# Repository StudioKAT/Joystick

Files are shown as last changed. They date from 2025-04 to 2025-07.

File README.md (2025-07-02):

# Joystick
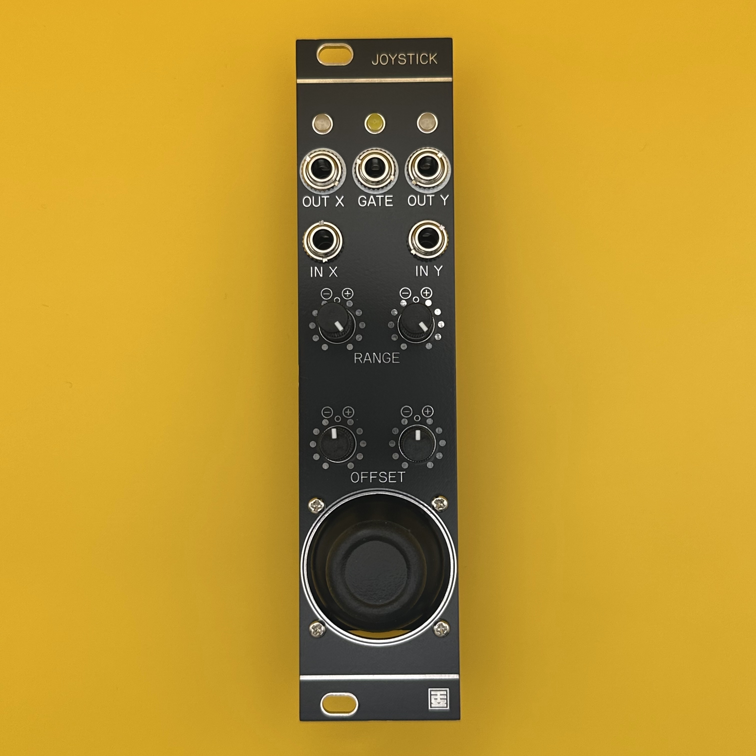
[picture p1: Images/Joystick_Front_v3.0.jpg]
Joystick Front


## 概要 / Overview

**Joystick** は、6HPサイズの片手操作に特化したマニュアルCV/Gate生成モジュールです。  
XY入力端子に外部CVを接続することで、アッテネーターやインバーターとしても利用可能です。  
CVレンジとオフセットはX軸・Y軸ごとに個別に調整でき、最大±10Vの範囲で任意のCVを生成できます。  
スティックを押し込むと、+10VのGate信号が出力されます。

**Joystick** is a 6HP manual CV/Gate generator module designed for one-handed operation.  
By connecting external CV signals to the X and Y inputs, it can also function as an attenuator or inverter.  
Each axis (X and Y) features independent control over CV range and offset, allowing for custom voltage outputs up to ±10V.  
Pressing the joystick down outputs a +10V Gate signal.

## 仕様 / Spec
- Format: Eurorack
- Function: Attenuator-Inverter joystick controller and Gate Generator.
- Current needs: +12V: 35mA, -12V: 35mA
- Width: 6 HP
- Depth: 25mm (including power connector)

## 動画 / Movie
'Joystick商品説明動画' (https://youtu.be/lRxTDCcPD24)

## 販売 / Sales

StudioKATオフィシャルショップで販売しています。(日本国内限定)  
https://www.studiokat.jp/items/106541452

## ライセンス / License

この作品は [Creative Commons 表示 - 継承 4.0 国際 (CC BY-SA 4.0)](https://creativecommons.org/licenses/by-sa/4.0/deed.ja) の下でライセンスされています。  
This work is licensed under the [Creative Commons Attribution-ShareAlike 4.0 International License](https://creativecommons.org/licenses/by-sa/4.0/).

## クレジット / Credits

- Designed by : StudioKAT
- Website : https://www.studiokat.jp/
- GitHub : https://github.com/StudioKAT
- X(Twitter) : https://x.com/StudioKAT_synth
- Instagram : https://www.instagram.com/studiokat_modular/

## 更新履歴 / Changelog

- `2024-09-28` v1.0 Unreleased
- `2025-04-24` v2.0 Released
- `2025-07-02` v3.0 Released

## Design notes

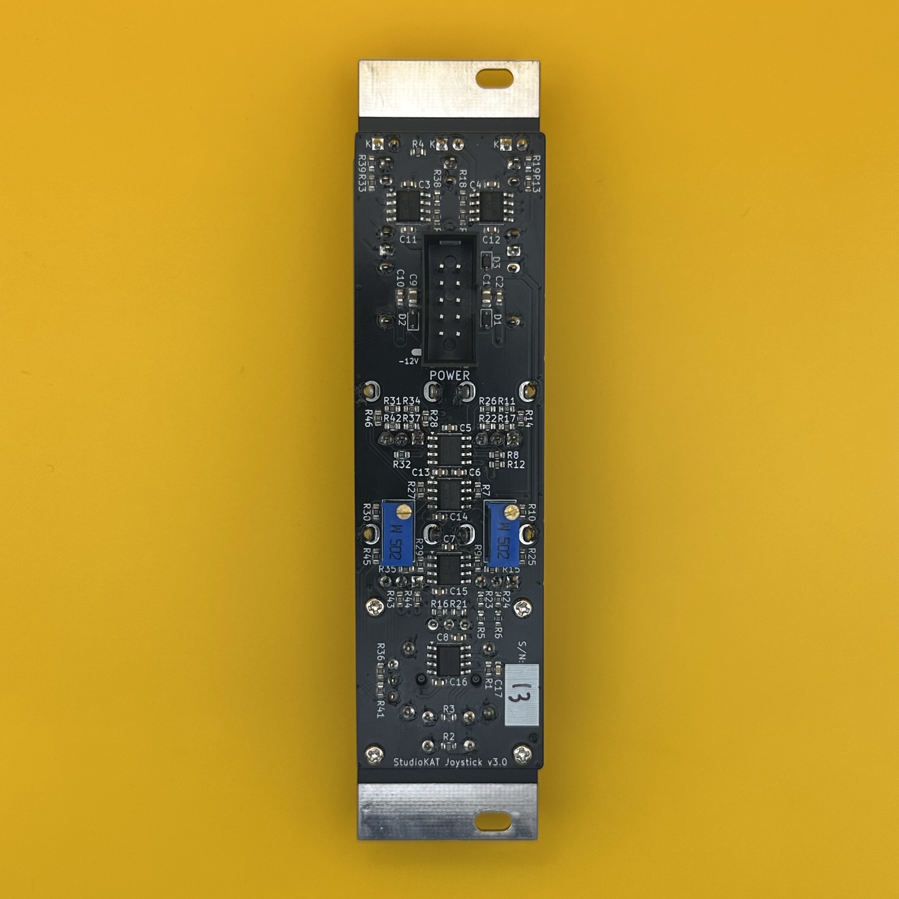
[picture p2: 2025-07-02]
Images/Joystick_Back_v3.0.jpg

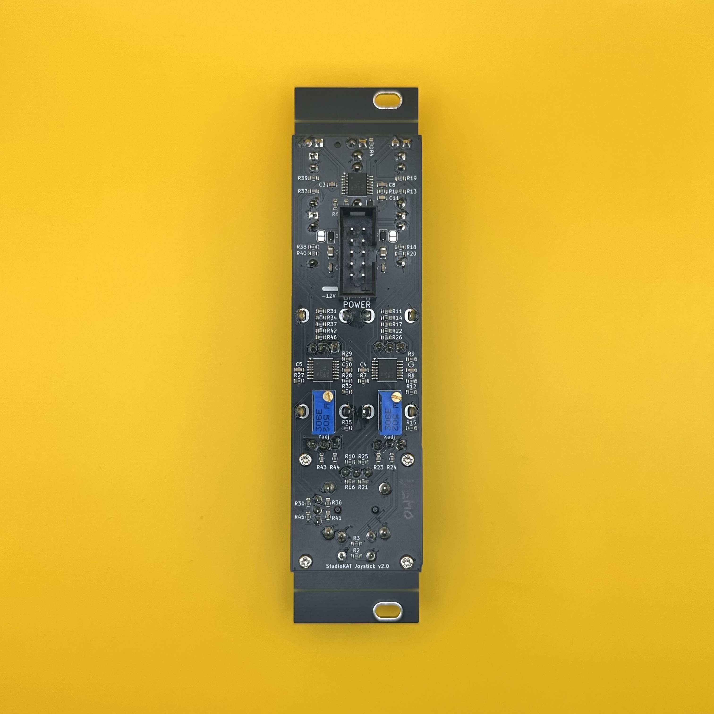
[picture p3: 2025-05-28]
Images/Joystick_Back.jpeg

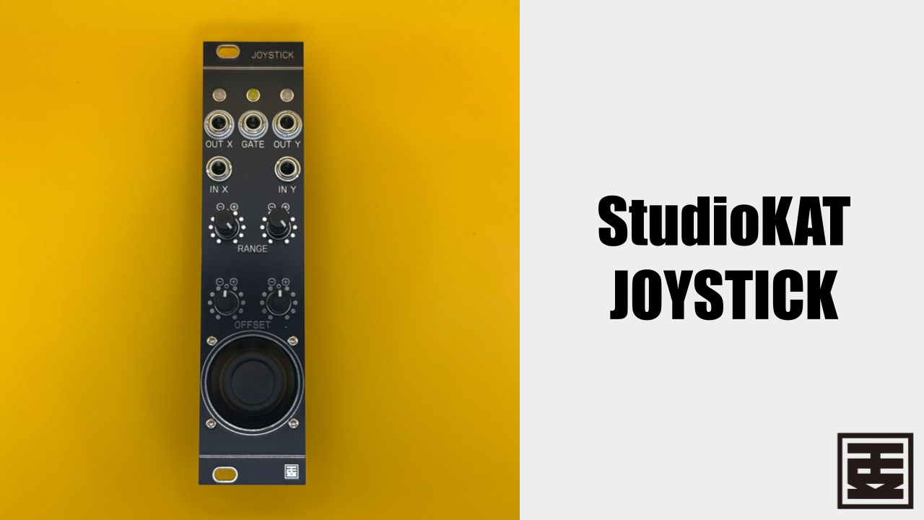
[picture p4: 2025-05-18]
Images/Joystick_thumbnail.png

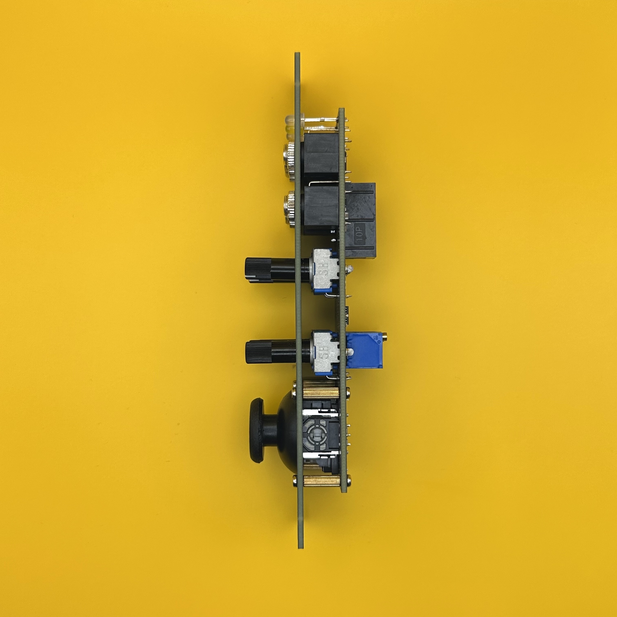
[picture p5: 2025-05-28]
Images/Joystick_Side.jpeg

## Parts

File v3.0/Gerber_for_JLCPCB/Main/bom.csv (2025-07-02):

Designator | Footprint | Quantity | Value | LCSC Part #
C1, C9 | 0805 | 2 | 22uF | C45783
C10, C11, C12, C13, C14, C15, C16, C2, C3, C4, C5, C6, C7, C8 | 0603 | 14 | 100nF | C14663
C17 | 0603 | 1 | 22nF | C21122
D1, D2 | D_SOD-323 | 2 | 1N5819WS | C191023
D3 | D_SOD-323 | 1 | 1N4148WS | C2128
D4 | LED_D3.0mm | 1 | LED
D5, D6 | LED_D3.0mm | 2 | LED_RED_GREEN
J1 | BoxHeader_2x05_2.54mm_Europower | 1 | POWER
J2 | AudioJack_PJ301M-12 | 1 | GATE
J3 | AudioJack_PJ301M-12 | 1 | X_OUT
J4 | AudioJack_PJ301M-12 | 1 | X_IN
J5 | AudioJack_PJ301M-12 | 1 | Y_OUT
J6 | AudioJack_PJ301M-12 | 1 | Y_IN
JS1 | Joystick_RKJXV122400R | 1 | RKJXV122400R
R1, R18, R38 | 0603 | 3 | 1M | C22935
R10, R12, R15, R20, R25, R27, R29, R30, R32, R35, R40, R45, R6, R7, R9 | 0603 | 15 | 10K | C25804
R11, R2, R26, R31, R46 | 0603 | 5 | 100K | C25803
R13, R23, R24, R33, R43, R44 | 0603 | 6 | 1K | C21190
R14, R34 | 0603 | 2 | 22K | C31850
R16, R36 | 0603 | 2 | 5.1K | C23186
R17, R37 | 0603 | 2 | 39K | C23153
R19, R39 | 0603 | 2 | 3.3K | C22978
R21, R41 | 0603 | 2 | 8.2K | C25981
R22, R42 | 0603 | 2 | 82K | C23254
R28, R8 | 0603 | 2 | 150K | C22807
R3 | 0603 | 1 | 470K | C23178
R4 | 0603 | 1 | 6.8K | C23212
R5 | 0603 | 1 | 4.7K | C23162
RV1, RV4 | Potentiometer_Bourns_3296W_Vertical | 2 | 5kΩ 502
RV2, RV3, RV5, RV6 | Potentiometer_RV09 | 4 | B100K
U1, U2, U3, U4, U5, U6 | SOIC-8_3.9x4.9mm_P1.27mm | 6 | TL072CDT | C6961

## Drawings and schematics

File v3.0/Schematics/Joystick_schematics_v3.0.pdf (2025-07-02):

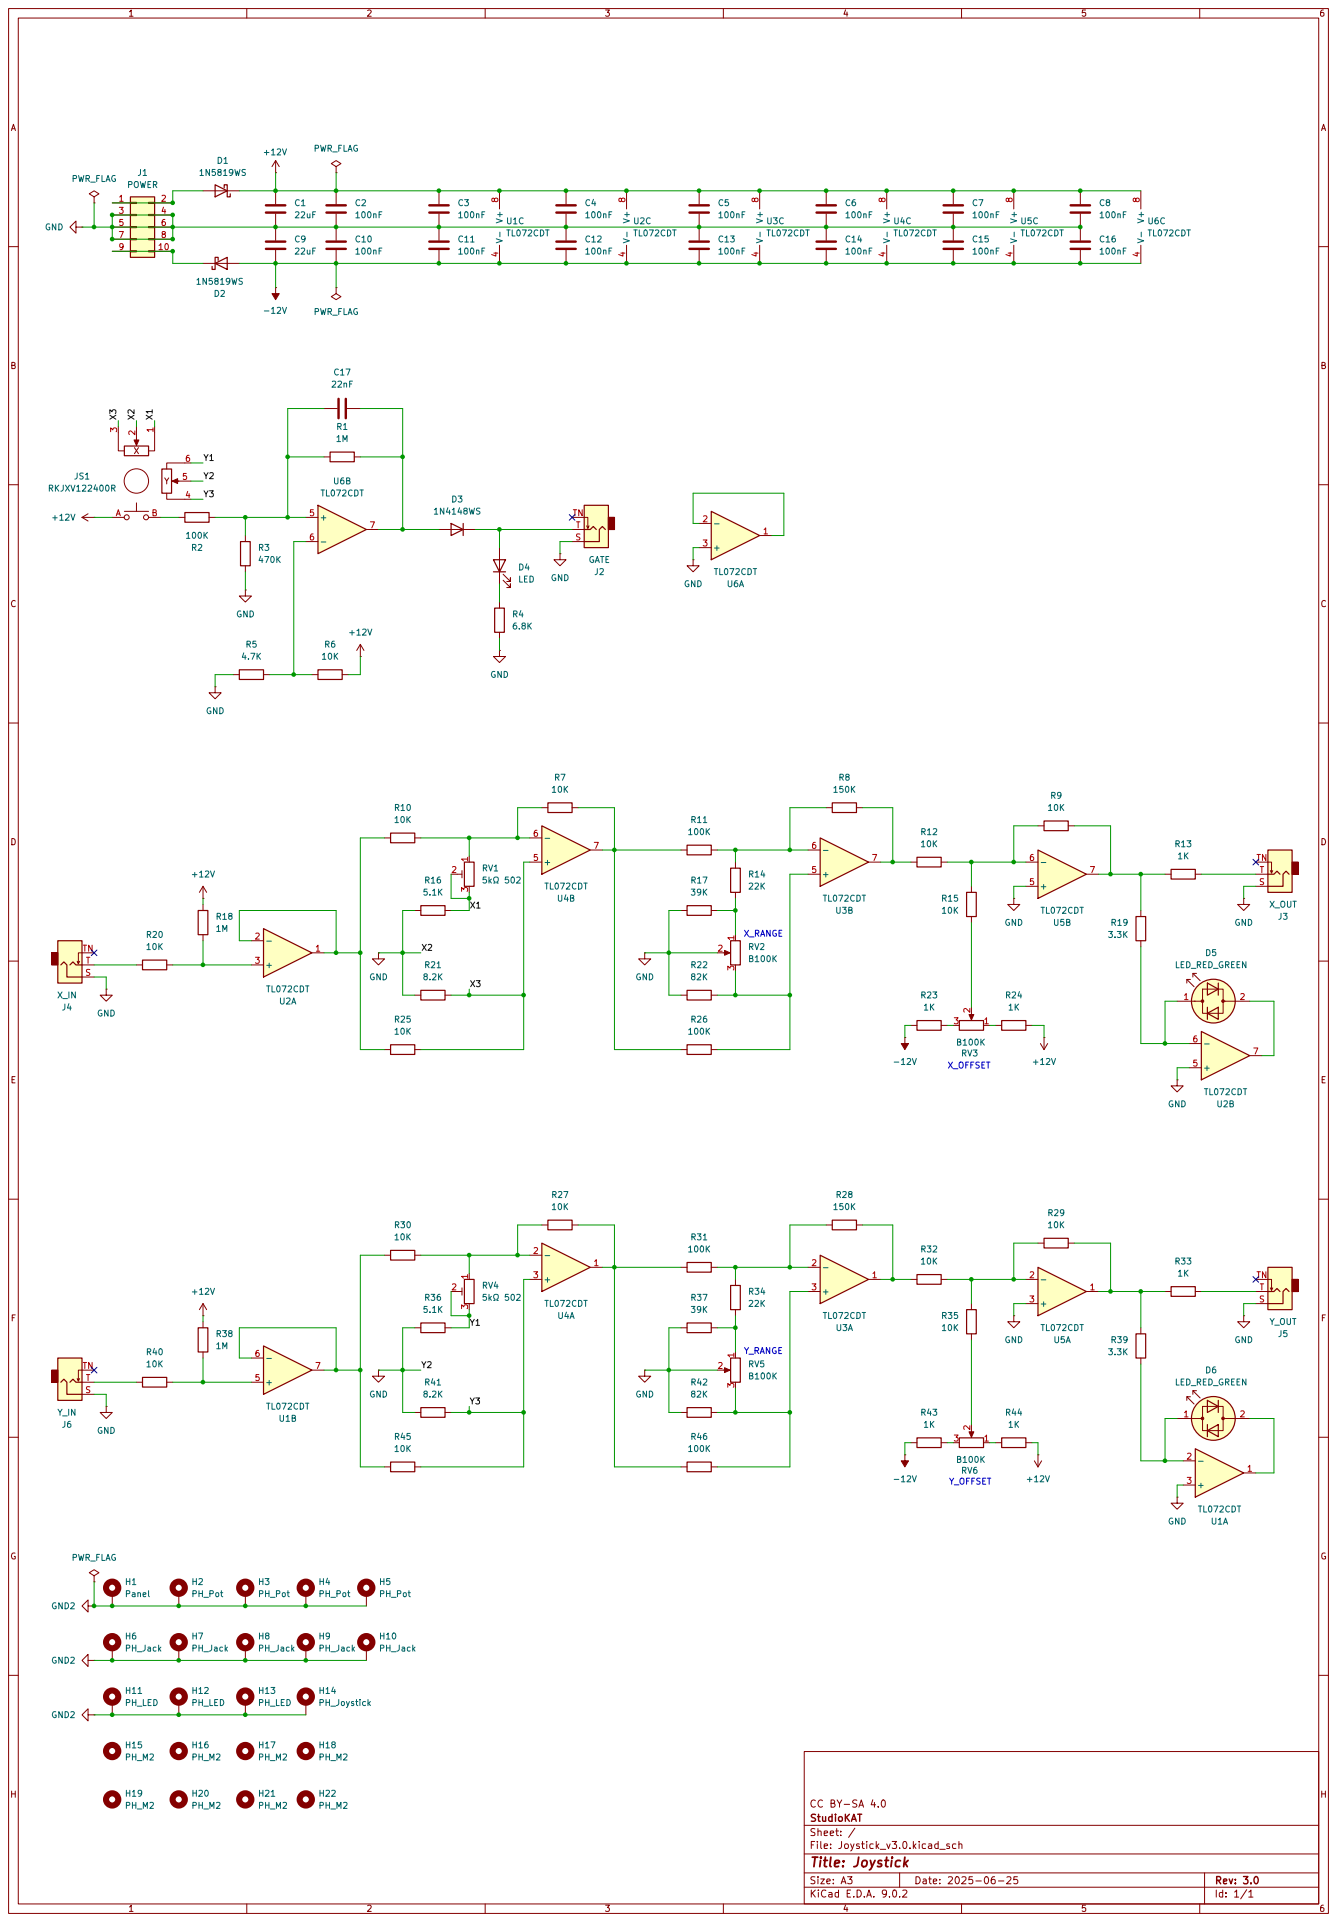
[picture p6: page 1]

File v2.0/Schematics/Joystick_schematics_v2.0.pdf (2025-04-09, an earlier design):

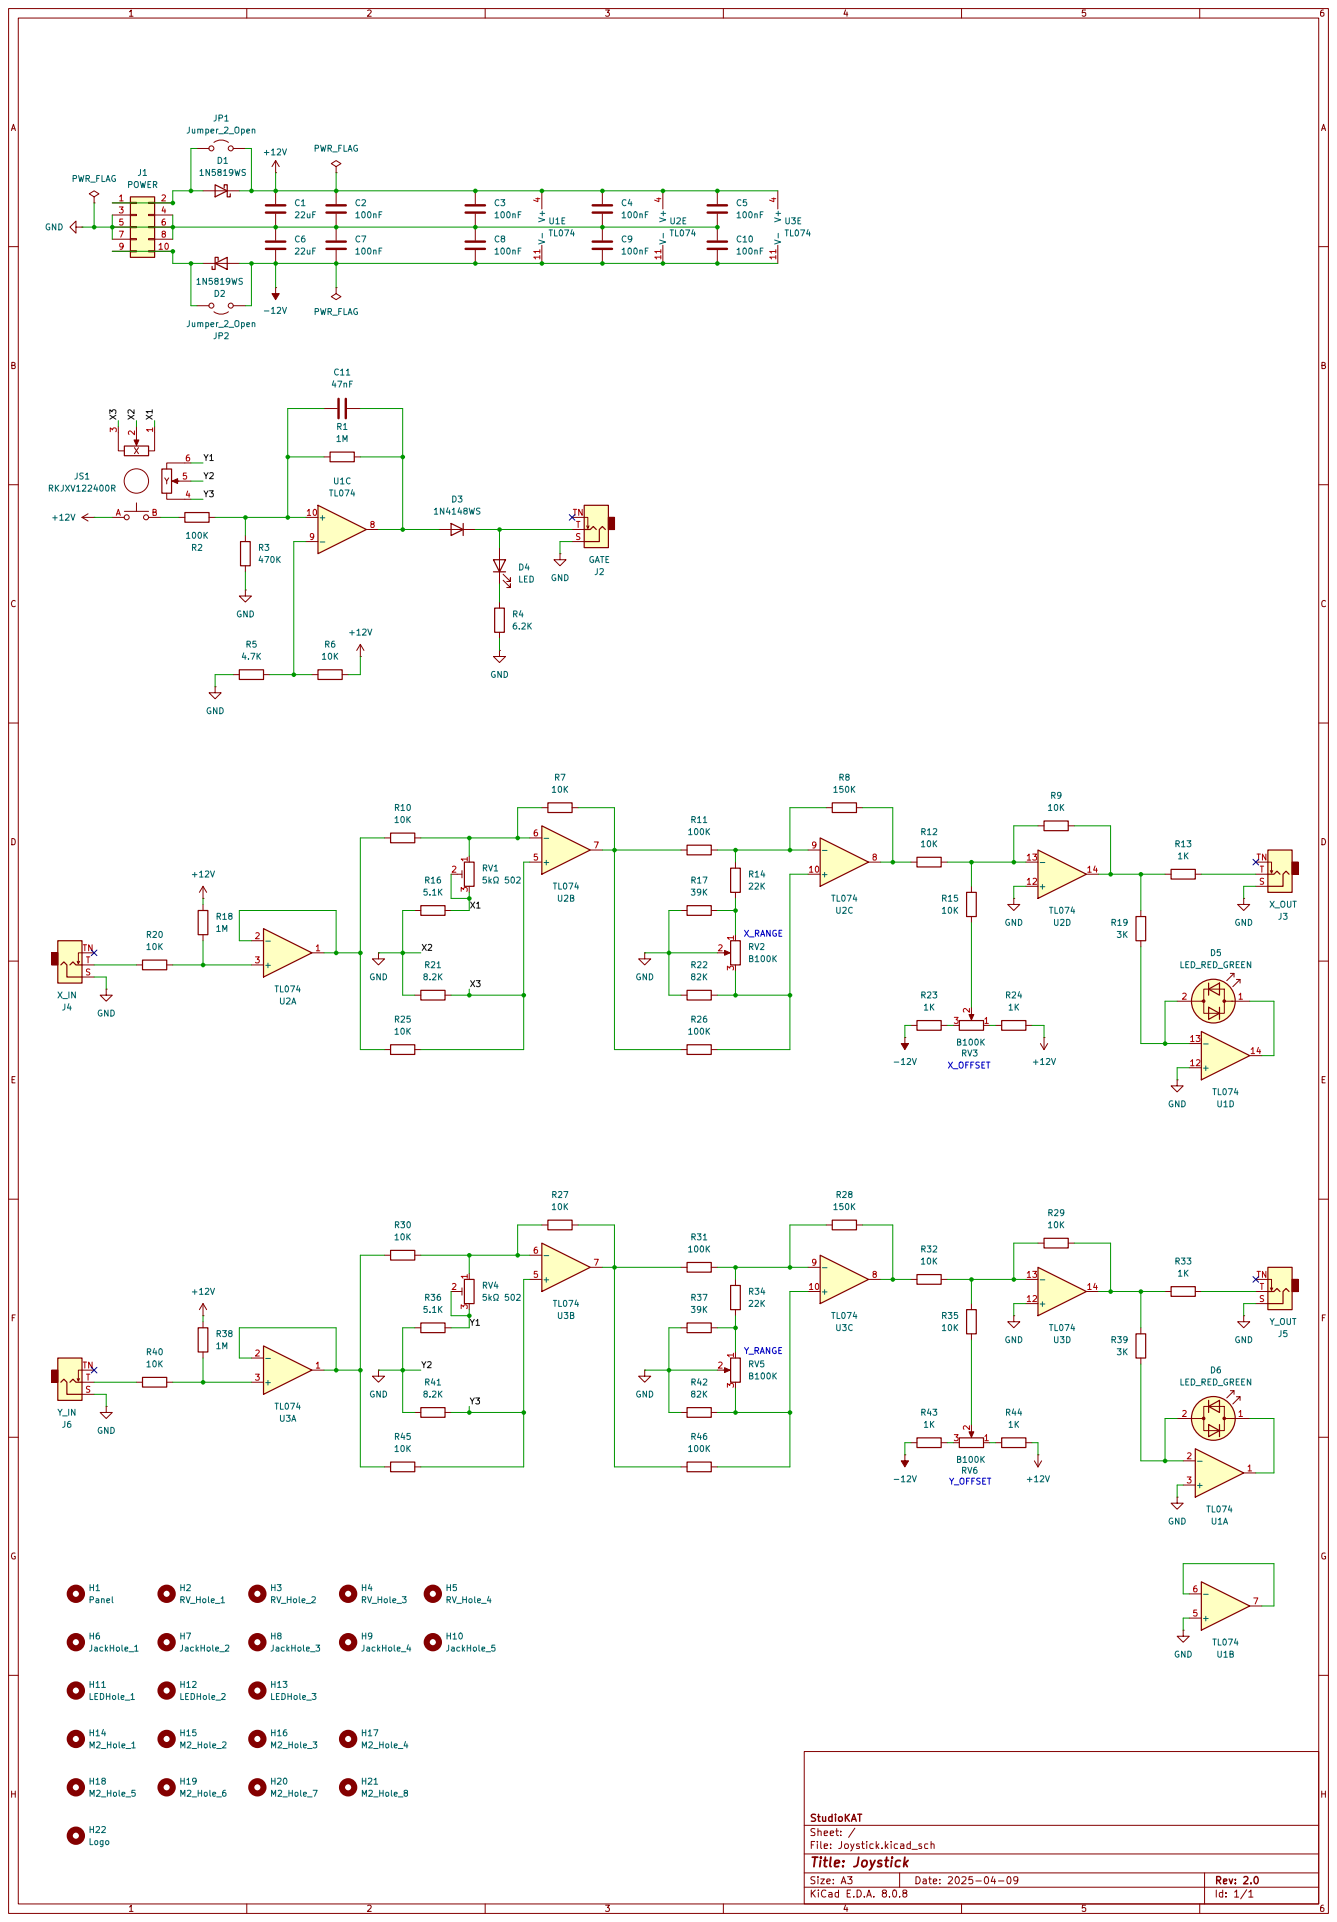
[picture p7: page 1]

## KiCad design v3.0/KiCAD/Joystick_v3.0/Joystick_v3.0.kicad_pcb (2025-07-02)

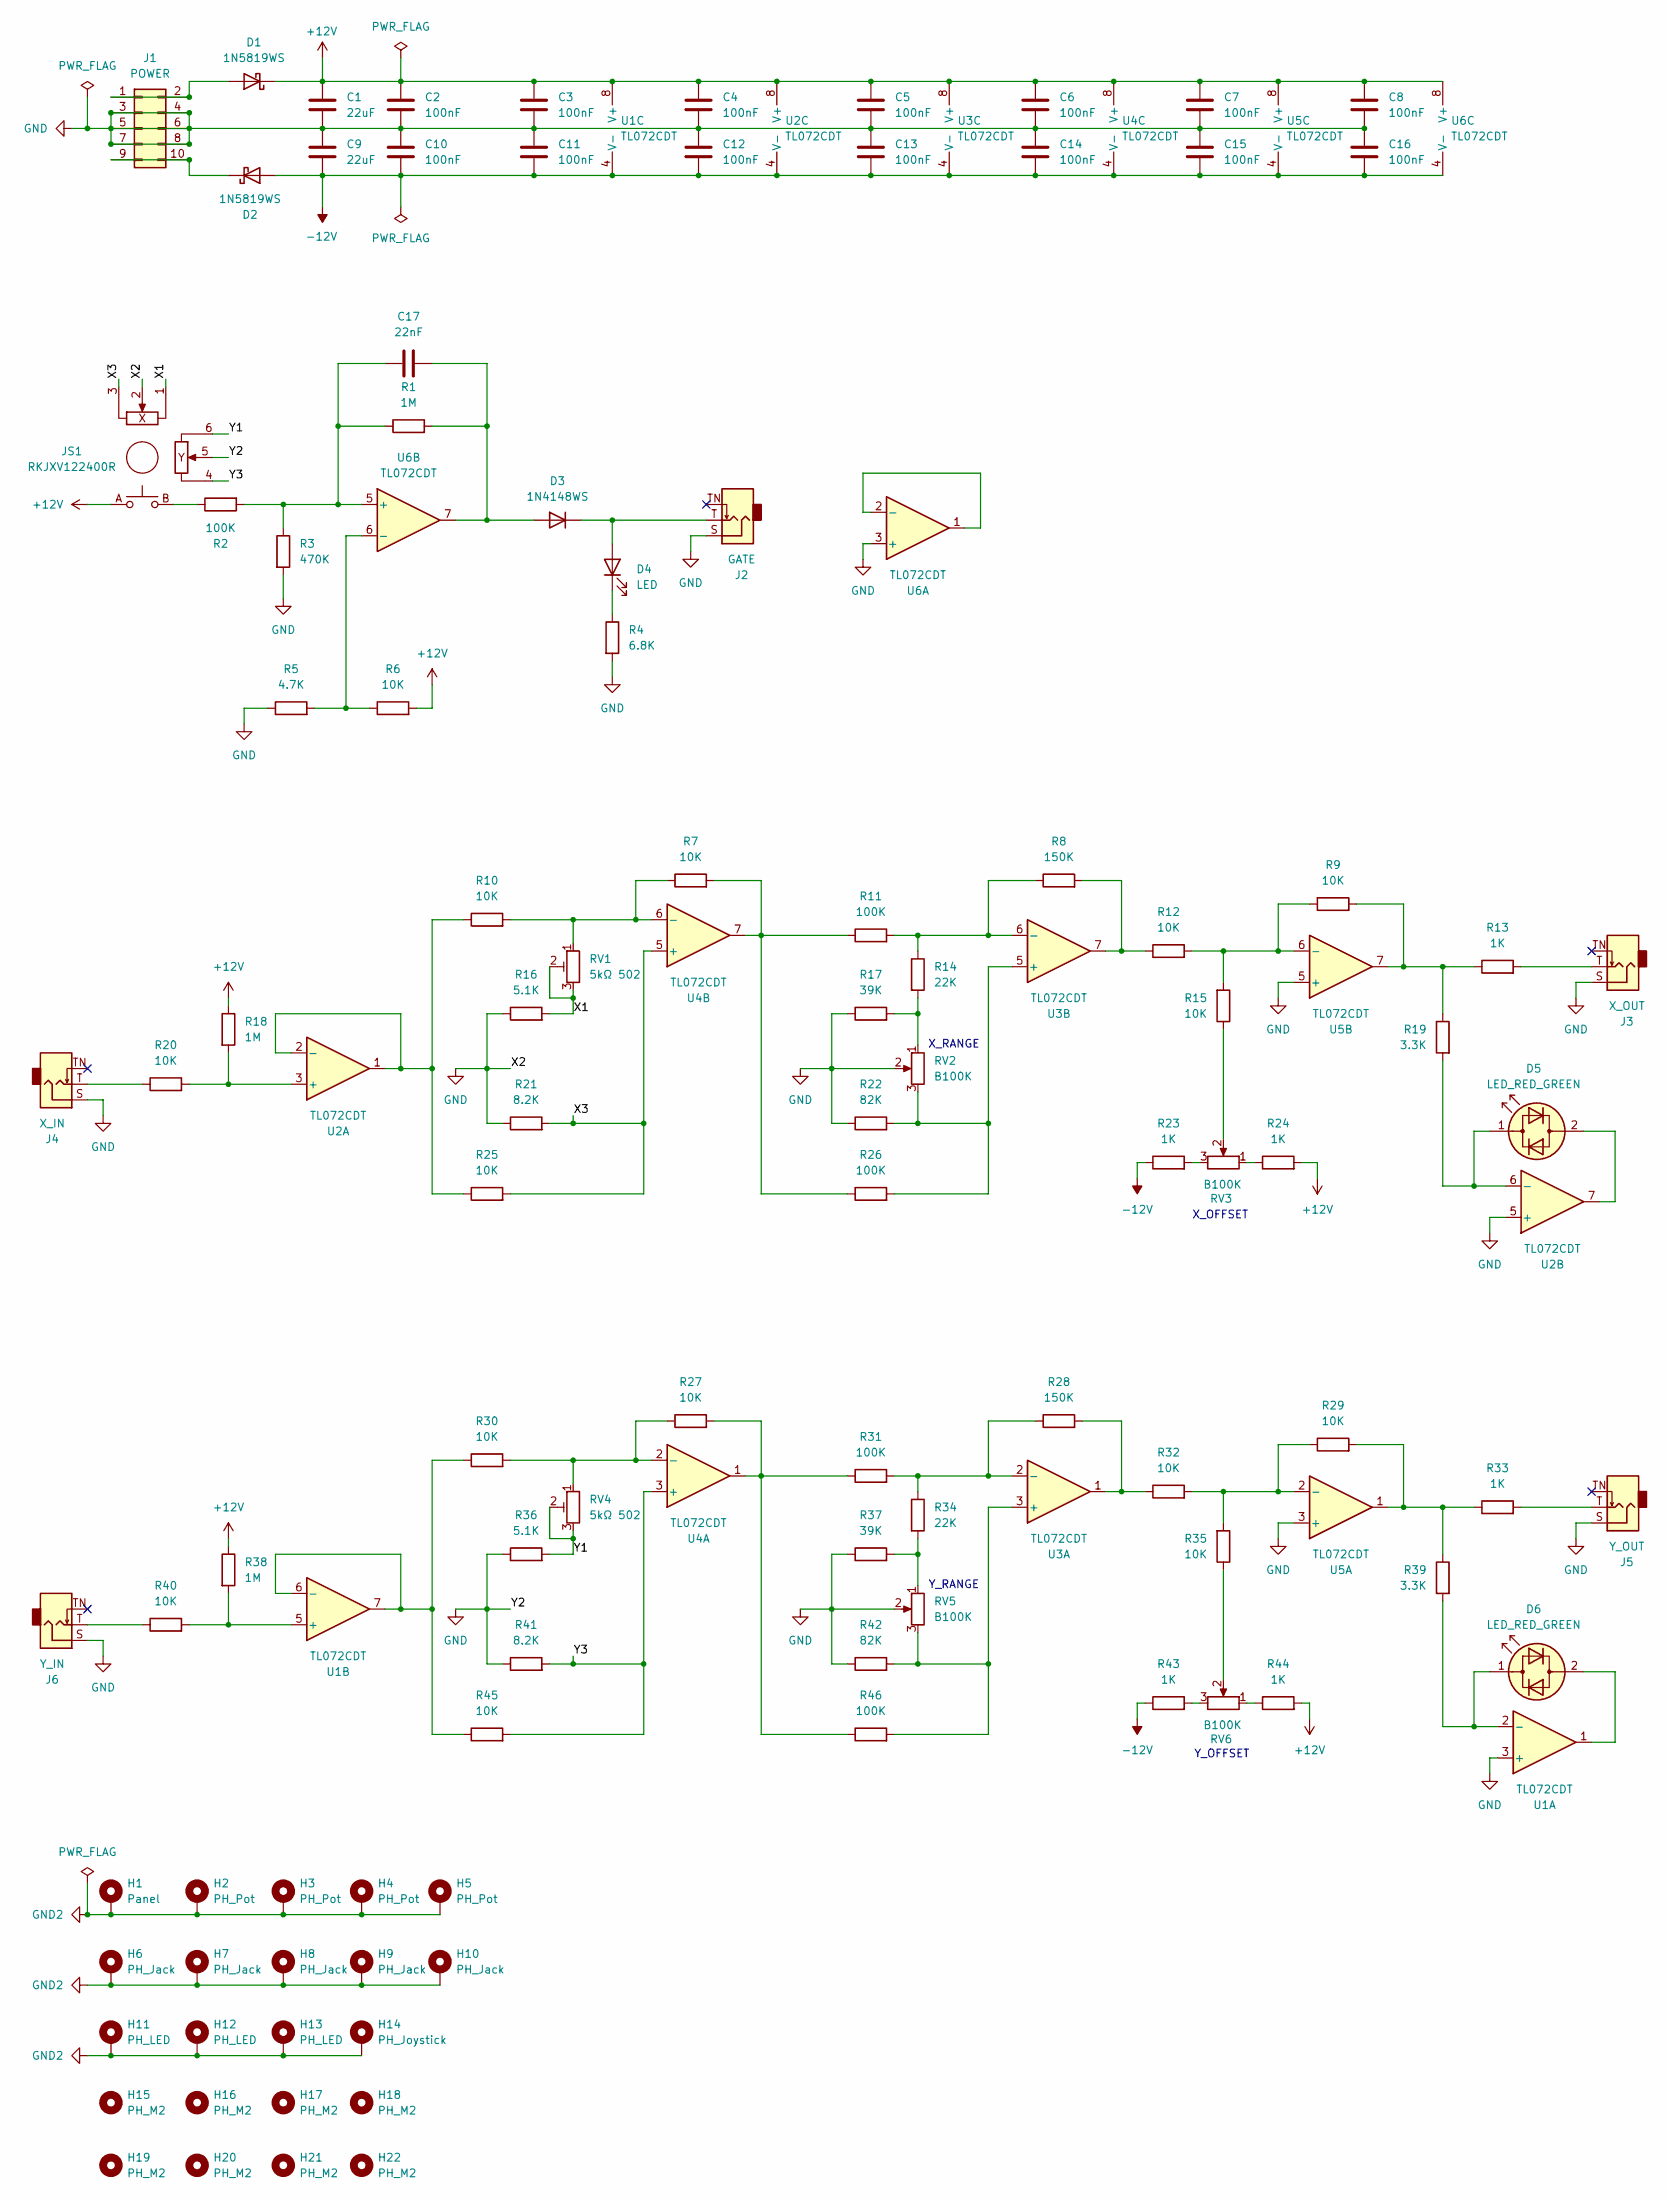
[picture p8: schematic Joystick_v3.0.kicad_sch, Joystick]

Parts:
C1, C9: 22uF; C_0805_2012Metric; LCSC C45783
C2, C3, C4, C5, C6, C7, C8, C10, C11, C12, C13, C14, C15, C16: 100nF; C_0603_1608Metric; LCSC C14663
C17: 22nF; C_0603_1608Metric; LCSC C21122
D1, D2: 1N5819WS; D_SOD-323; LCSC C191023
D3: 1N4148WS; D_SOD-323; LCSC C2128
D4: LED; LED_D3.0mm
D5, D6: LED_RED_GREEN; LED_D3.0mm
H1: Panel; Panel_6HP
H2, H3, H4, H5: PH_Pot; PH_RV09_center
H6, H7, H8, H9, H10: PH_Jack; PH_AudioJack_3.5mm_Pad
H11, H12, H13: PH_LED; PH_LED_3.0mm_Pad
H14: PH_Joystick
H15, H16, H17, H18, H19, H20, H21, H22: PH_M2; MountingHole_2.2mm_M2
J1: POWER; BoxHeader_2x05_2.54mm_Europower
J2: GATE; AudioJack_PJ301M-12
J3: X_OUT; AudioJack_PJ301M-12
J4: X_IN; AudioJack_PJ301M-12
J5: Y_OUT; AudioJack_PJ301M-12
J6: Y_IN; AudioJack_PJ301M-12
JS1: RKJXV122400R; Joystick_RKJXV122400R
R1, R18, R38: 1M; R_0603_1608Metric; LCSC C22935
R2, R11, R26, R31, R46: 100K; R_0603_1608Metric; LCSC C25803
R3: 470K; R_0603_1608Metric; LCSC C23178
R4: 6.8K; R_0603_1608Metric; LCSC C23212
R5: 4.7K; R_0603_1608Metric; LCSC C23162
R6, R7, R9, R10, R12, R15, R20, R25, R27, R29, R30, R32, R35, R40, R45: 10K; R_0603_1608Metric; LCSC C25804
R8, R28: 150K; R_0603_1608Metric; LCSC C22807
R13, R23, R24, R33, R43, R44: 1K; R_0603_1608Metric; LCSC C21190
R14, R34: 22K; R_0603_1608Metric; LCSC C31850
R16, R36: 5.1K; R_0603_1608Metric; LCSC C23186
R17, R37: 39K; R_0603_1608Metric; LCSC C23153
R19, R39: 3.3K; R_0603_1608Metric; LCSC C22978
R21, R41: 8.2K; R_0603_1608Metric; LCSC C25981
R22, R42: 82K; R_0603_1608Metric; LCSC C23254
RV1, RV4: 5kΩ 502; Potentiometer_Bourns_3296W_Vertical
RV2, RV3, RV5, RV6: B100K; Potentiometer_RV09
U1, U2, U3, U4, U5, U6: TL072CDT; SOIC-8_3.9x4.9mm_P1.27mm; LCSC C6961

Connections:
+12V: C1.1, C2.1, C3.1, C4.1, C5.1, C6.1, C7.1, C8.1, D1.1 (K), JS1.A, R6.2, R18.1, R24.2, R38.1, R44.2, U1.8 (V+), U2.8 (V+), U3.8 (V+), U4.8 (V+), U5.8 (V+), U6.8 (V+)
-12V: C9.2, C10.2, C11.2, C12.2, C13.2, C14.2, C15.2, C16.2, D2.2 (A), R23.1, R43.1, U1.4 (V-), U2.4 (V-), U3.4 (V-), U4.4 (V-), U5.4 (V-), U6.4 (V-)
/X1: JS1.1, R16.2, RV1.2, RV1.3
/X3: JS1.3, R21.2, R25.2, U4.5 (+)
/Y1: JS1.6, R36.2, RV4.2, RV4.3
/Y3: JS1.4, R41.2, R45.2, U4.3 (+)
GND: C1.2, C2.2, C3.2, C4.2, C5.2, C6.2, C7.2, C8.2, C9.1, C10.1, C11.1, C12.1, C13.1, C14.1, C15.1, C16.1, J1.3, J1.4, J1.5, J1.6, J1.7, J1.8, J2.S, J3.S, J4.S, J5.S, J6.S, JS1.2, JS1.5, R3.2, R4.2, R5.1, R16.1, R17.1, R21.1, R22.1, R36.1, R37.1, R41.1, R42.1, RV2.2, RV5.2, U1.3 (+), U2.5 (+), U5.3 (+), U5.5 (+), U6.3 (+)
GND2: H1.1, H2.1, H3.1, H4.1, H5.1, H6.1, H7.1, H8.1, H9.1, H10.1, H11.1, H12.1, H13.1, H14.1
unnamed: D1.2 (A), J1.1, J1.2
unnamed: D2.1 (K), J1.9, J1.10
unnamed: C17.2, D3.2 (A), R1.2, U6.7
unnamed: D3.1 (K), D4.2 (A), J2.T
unnamed: D4.1 (K), R4.1
unnamed: D5.2 (AK), U2.7
unnamed: D5.1 (KA), R19.2, U2.6 (-)
unnamed: D6.2 (AK), U1.1
unnamed: D6.1 (KA), R39.2, U1.2 (-)
unnamed: J3.T, R13.2
unnamed: J4.T, R20.1
unnamed: J5.T, R33.2
unnamed: J6.T, R40.1
unnamed: JS1.B, R2.1
unnamed: R7.2, R11.1, R26.1, U4.7
unnamed: R8.2, R12.1, U3.7
unnamed: R9.2, R13.1, R19.1, U5.7
unnamed: R14.2, R17.2, RV2.1
unnamed: R15.1, RV3.2
unnamed: R23.2, RV3.3
unnamed: R24.1, RV3.1
unnamed: R27.2, R31.1, R46.1, U4.1
unnamed: R28.2, R32.1, U3.1
unnamed: R29.2, R33.1, R39.1, U5.1
unnamed: R34.2, R37.2, RV5.1
unnamed: R35.1, RV6.2
unnamed: R43.2, RV6.3
unnamed: R44.1, RV6.1
unnamed: R38.2, R40.2, U1.5 (+)
unnamed: R30.1, R45.1, U1.6 (-), U1.7
unnamed: R18.2, R20.2, U2.3 (+)
unnamed: R10.1, R25.1, U2.1, U2.2 (-)
unnamed: R42.2, R46.2, RV5.3, U3.3 (+)
unnamed: R28.1, R31.2, R34.1, U3.2 (-)
unnamed: R22.2, R26.2, RV2.3, U3.5 (+)
unnamed: R8.1, R11.2, R14.1, U3.6 (-)
unnamed: R27.1, R30.2, RV4.1, U4.2 (-)
unnamed: R7.1, R10.2, RV1.1, U4.6 (-)
unnamed: R29.1, R32.2, R35.2, U5.2 (-)
unnamed: R9.1, R12.2, R15.2, U5.6 (-)
unnamed: U6.1, U6.2 (-)
unnamed: C17.1, R1.1, R2.2, R3.1, U6.5 (+)
unnamed: R5.2, R6.1, U6.6 (-)

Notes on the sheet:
Y_RANGE
X_OFFSET
X_RANGE
Y_OFFSET

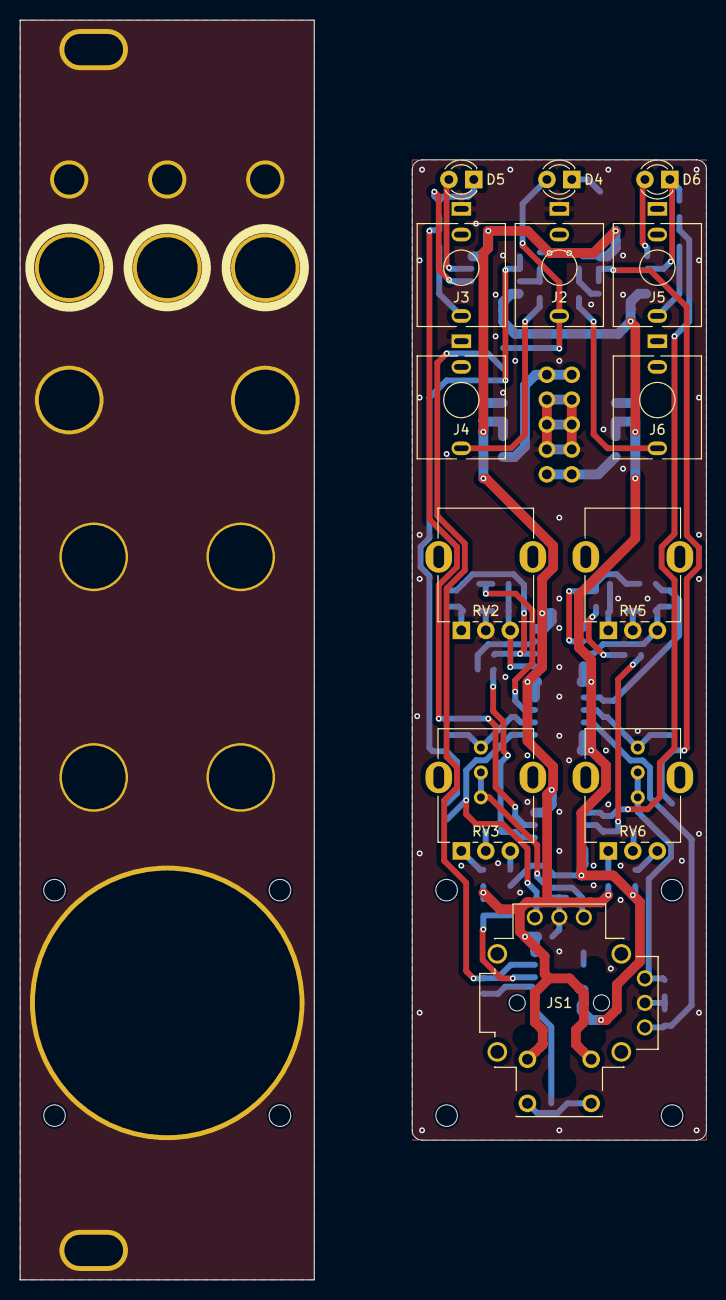
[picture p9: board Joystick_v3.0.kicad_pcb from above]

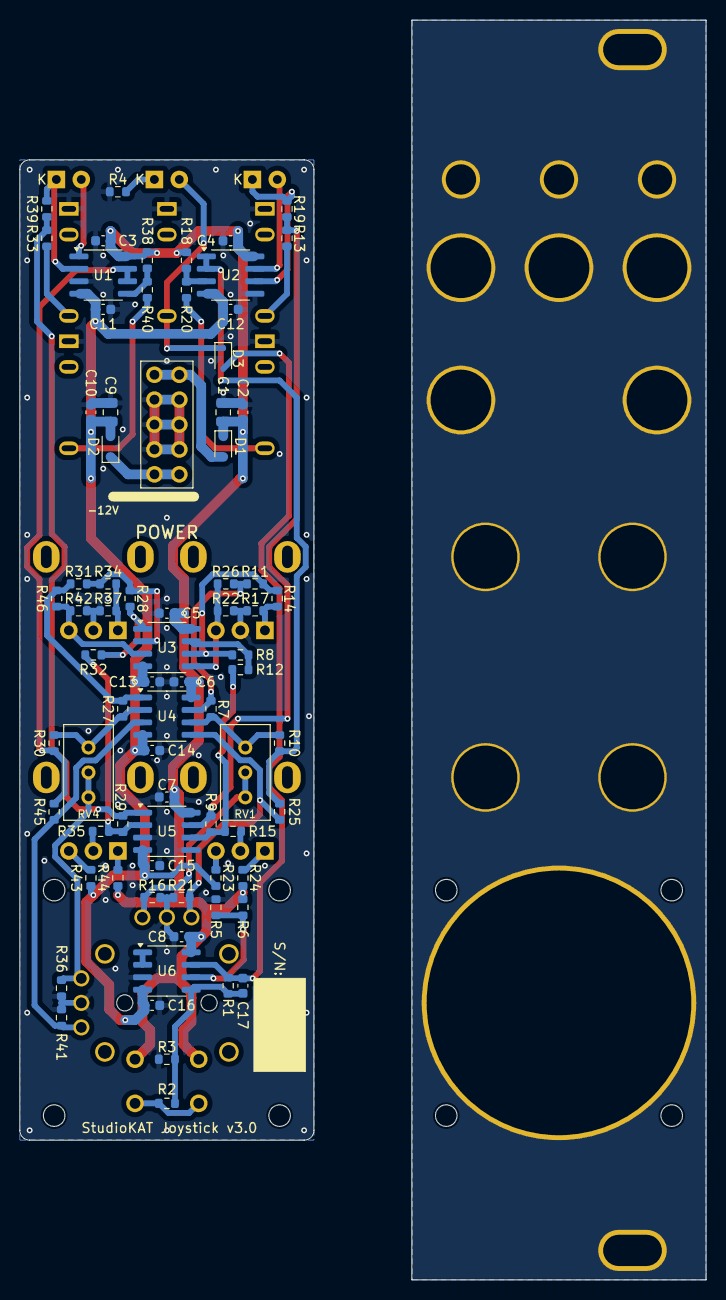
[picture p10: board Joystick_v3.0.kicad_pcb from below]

Board: 2 copper layers, 30.0 x 100.0 mm, 110 parts (75 on the bottom side), 51 nets.

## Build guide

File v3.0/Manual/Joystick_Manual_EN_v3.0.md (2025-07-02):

# Joystick Manual (English)

Joystick Front

## Overview

**Joystick** is a 6HP module designed for one-handed manual control of CV and Gate signals.  
By patching external CV into the XY inputs, it can also function as an attenuverter or inverter.  
The CV range and offset are independently adjustable for each axis (X/Y), allowing output up to ±10V.  
Pushing the joystick down generates a +10V Gate signal.

## Specifications

- **Format**: Eurorack  
- **Width**: 6 HP  
- **Depth**: 25 mm  
- **Current Draw**: +12V: 35mA / -12V: 35mA  

> **IMPORTANT**: Make sure the red stripe on the ribbon cable connects to -12V.  
> Incorrect installation may cause permanent damage to the module.  
> **Always verify cable orientation before powering on.**

## Features

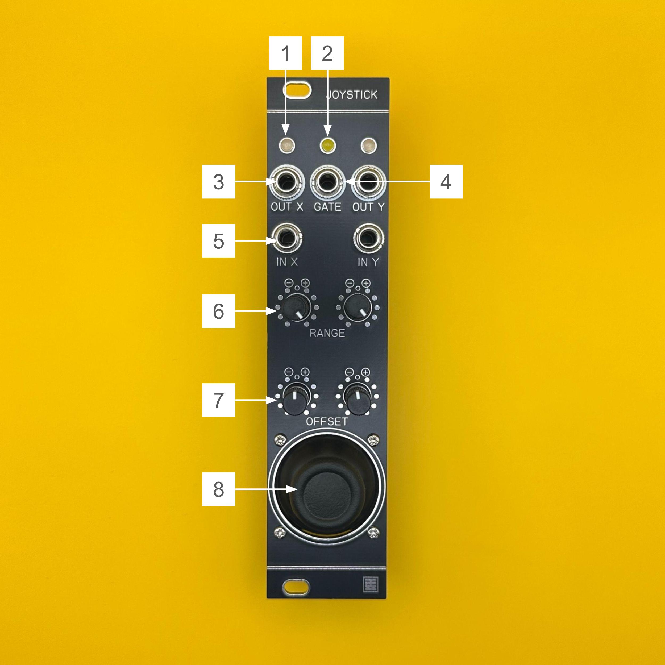
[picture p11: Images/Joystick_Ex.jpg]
explanation


1. **LED (X/Y)**  
   Indicates the amplitude and polarity of the CV output.  
   Green = positive voltage, Red = negative voltage.

2. **LED (GATE)**  
   Indicates Gate signal status.  
   Lit in yellow when HIGH, off when LOW.

3. **OUT X/Y**  
   CV output for the X or Y axis.  
   Output range: up to ±10V.

4. **GATE**  
   Outputs +10V while the joystick is pressed down.

5. **IN X/Y**  
   By default, internally normalized to +10V.  
   When an external CV is connected, internal voltage is bypassed, and the joystick acts as an attenuverter for the input signal.

6. **RANGE**  
   Attenuverter for the internal +10V or the input CV signal.  
   Full left: -1×, center: 0V, full right: +1×.

7. **OFFSET**  
   Adds a DC offset to the CV output.  
   Range: -10V (left), 0V (center), +10V (right).

8. **JOYSTICK**  
   Supports motion on the X/Y axes and push (Z).  
   Returns to center position when released.

> When the joystick is pushed fully in one direction, it may not return to center automatically (this is intentional).  
> Due to analog circuit characteristics, the CV output may not be exactly 0V when the stick is centered.  
> Use the **OFFSET knob** to fine-tune as needed.

## License

This work is licensed under a [Creative Commons Attribution-ShareAlike 4.0 International License (CC BY-SA 4.0)](https://creativecommons.org/licenses/by-sa/4.0/).

## Credits

- **Designed by**: StudioKAT  
- **Website**: [https://www.studiokat.jp/](https://www.studiokat.jp/)  
- **GitHub**: [https://github.com/StudioKAT](https://github.com/StudioKAT)  
- **X (Twitter)**: [https://x.com/StudioKAT_synth](https://x.com/StudioKAT_synth)  
- **Instagram**: [https://www.instagram.com/studiokat_modular/](https://www.instagram.com/studiokat_modular/)

## Changelog

- `2024-09-28`: v1.0 (Not released due to PCB design issue)  
- `2025-04-24`: v2.0 Released  
- `2025-07-02`: v3.0 Released

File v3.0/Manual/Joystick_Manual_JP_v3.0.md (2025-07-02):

# Joystick マニュアル（日本語）

Joystick Front

## 概要

**Joystick** は、6HPサイズの片手操作に特化したマニュアルCV／Gate生成モジュールです。  
XY入力端子に外部CVを接続することで、アッテネーターやインバーターとしても使用可能です。  
CVレンジおよびオフセットはX軸・Y軸ごとに個別に調整可能で、最大±10Vの範囲で任意のCVを生成できます。  
スティックを押し込むと、+10VのGate信号が出力されます。

## 仕様

- **フォーマット**：Eurorack  
- **幅**：6 HP  
- **奥行き**：25 mm  
- **消費電流**：+12V: 35mA / -12V: 35mA  

> ※ ケーブルの赤いラインが -12V に接続されるようにしてください。  
> 誤って接続するとモジュールが故障する恐れがあります。  
> **電源投入前に必ずケーブルの向きを確認してください。**

## 各部の機能

explanation

1. **LED (X/Y)**  
   CV出力信号の振幅と極性を表示します。  
   プラス出力時は緑、マイナス出力時は赤に点灯します。

2. **LED (GATE)**  
   GATE信号のON／OFFを表示します。  
   HIGHで黄点灯、LOWで消灯します。

3. **OUT X/Y**  
   XまたはY軸方向のCV出力端子です。  
   出力範囲は最大±10Vです。

4. **GATE**  
   ジョイスティックを押し込んでいる間、+10VのGATE信号を出力します。

5. **IN X/Y**  
   デフォルトでは内部で+10Vが供給されています。  
   外部CVを接続すると内部電圧は遮断され、ジョイスティックはそのCV信号に対するアッテヌバーターとして動作します。

6. **RANGE**  
   IN端子および内部+10Vに対するアッテヌバーターです。  
   左端で-1倍、中央で0V、右端で+1倍となります。

7. **OFFSET**  
   CV出力に加える直流オフセット電圧を調整します。  
   左端で-10V、中央で0V、右端で+10Vになります。

8. **JOYSTICK**  
   X／Y方向および押し込み（Z）に対応したジョイスティックです。  
   指を離すと自動的にセンターへ戻ります。

> ジョイスティックを最大まで倒すと、センターに戻らないことがあります（仕様）。  
> アナログ回路の特性上、スティックのセンター位置でCV出力が正確に0Vとならないことがあります。  
> 必要に応じて**OFFSETノブ**で微調整してください。

## ライセンス

この作品は [Creative Commons 表示 - 継承 4.0 国際 (CC BY-SA 4.0)](https://creativecommons.org/licenses/by-sa/4.0/deed.ja) の下でライセンスされています。

## クレジット

- **Designed by**：StudioKAT  
- **Website**：[https://www.studiokat.jp/](https://www.studiokat.jp/)  
- **GitHub**：[https://github.com/StudioKAT](https://github.com/StudioKAT)  
- **X（旧Twitter）**：[https://x.com/StudioKAT_synth](https://x.com/StudioKAT_synth)  
- **Instagram**：[https://www.instagram.com/studiokat_modular/](https://www.instagram.com/studiokat_modular/)

## 更新履歴

- `2024-09-28`：v1.0（基板設計ミスにより未リリース）  
- `2025-04-24`：v2.0 リリース  
- `2025-07-02`：v3.0 リリース

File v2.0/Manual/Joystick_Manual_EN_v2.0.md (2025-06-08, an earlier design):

# Joystick Manual (English)

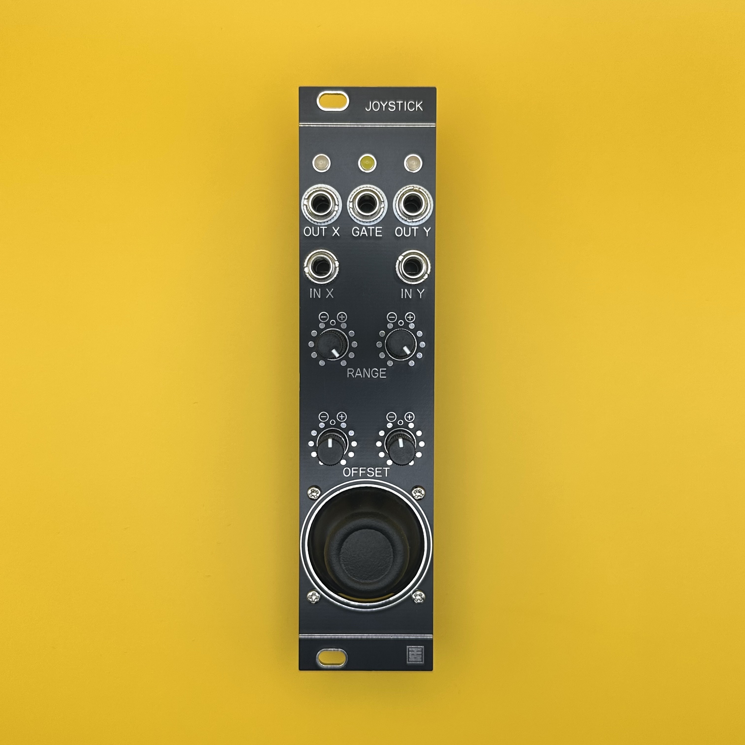
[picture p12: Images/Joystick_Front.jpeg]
Joystick Front


## Overview

**Joystick** is a 6HP module designed for one-handed manual control of CV and Gate signals.  
By patching external CV into the XY inputs, it can also function as an attenuverter or inverter.  
The CV range and offset are independently adjustable for each axis (X/Y), allowing output up to ±10V.  
Pushing the joystick down generates a +10V Gate signal.

---

## Specifications

- **Format**: Eurorack  
- **Width**: 6 HP  
- **Depth**: 25 mm  
- **Current Draw**: +12V: 35mA / -12V: 35mA  

> **IMPORTANT**: Make sure the red stripe on the ribbon cable connects to -12V.  
> Incorrect installation may cause permanent damage to the module.  
> **Always verify cable orientation before powering on.**

---

## Features

explanation

1. **LED (X/Y)**  
   Indicates the amplitude and polarity of the CV output.  
   Green = positive voltage, Red = negative voltage.

2. **LED (GATE)**  
   Indicates Gate signal status.  
   Lit in yellow when HIGH, off when LOW.

3. **OUT X/Y**  
   CV output for the X or Y axis.  
   Output range: up to ±10V.

4. **GATE**  
   Outputs +10V while the joystick is pressed down.

5. **IN X/Y**  
   By default, internally normalized to +10V.  
   When an external CV is connected, internal voltage is bypassed, and the joystick acts as an attenuverter for the input signal.

6. **RANGE**  
   Attenuverter for the internal +10V or the input CV signal.  
   Full left: -1×, center: 0V, full right: +1×.

7. **OFFSET**  
   Adds a DC offset to the CV output.  
   Range: -10V (left), 0V (center), +10V (right).

8. **JOYSTICK**  
   Supports motion on the X/Y axes and push (Z).  
   Returns to center position when released.

---

> When the joystick is pushed fully in one direction, it may not return to center automatically (this is intentional).  
> Due to analog circuit characteristics, the CV output may not be exactly 0V when the stick is centered.  
> Use the **OFFSET knob** to fine-tune as needed.

---

## License

This work is licensed under a [Creative Commons Attribution-ShareAlike 4.0 International License (CC BY-SA 4.0)](https://creativecommons.org/licenses/by-sa/4.0/).

---

## Credits

- **Designed by**: StudioKAT  
- **Website**: [https://www.studiokat.jp/](https://www.studiokat.jp/)  
- **GitHub**: [https://github.com/StudioKAT](https://github.com/StudioKAT)  
- **X (Twitter)**: [https://x.com/StudioKAT_synth](https://x.com/StudioKAT_synth)  
- **Instagram**: [https://www.instagram.com/studiokat_modular/](https://www.instagram.com/studiokat_modular/)

---

## Changelog

- `2024-09-28`: v1.0 (Not released due to PCB design issue)  
- `2025-04-24`: v2.0 Released

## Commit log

2025-04-09 README.md 誤字修正
2025-04-24 マニュアル追加
2025-04-30 消費電流を実測値に変更
2025-05-18 動画追加
2025-05-22 フォルダ構成変更、KiCADプロジェクト追加
    [Joystick_v2.0.kicad_pcb, Joystick_v2.0.kicad_sch, bom.csv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]
2025-05-22 README画像リンク切れ修正
2025-05-22 README画像リンク切れ修正_2
2025-05-28 画像差し替え
2025-06-08 ディレクトリ構成変更
2025-06-08 README更新
2025-06-08 フォルダ名変更
    [bom.csv, positions.csv]
2025-07-02 v3.0追加
    [Joystick_v3.0.kicad_pcb, Joystick_v3.0.kicad_sch, bom.csv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]
